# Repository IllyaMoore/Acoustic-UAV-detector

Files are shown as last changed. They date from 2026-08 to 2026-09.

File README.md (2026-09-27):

# Acoustic UAV Detector



A passive acoustic drone detector: three MEMS microphones on a 150 mm triangle
and an ESP32 that estimates the bearing to a drone from propeller noise
(TDOA, GCC-PHAT), over 360°. Several nodes can be fused into a position and
shown in ATAK.

It emits nothing, so it works without GNSS or radio, including under jamming,
and needs no transmit permit.

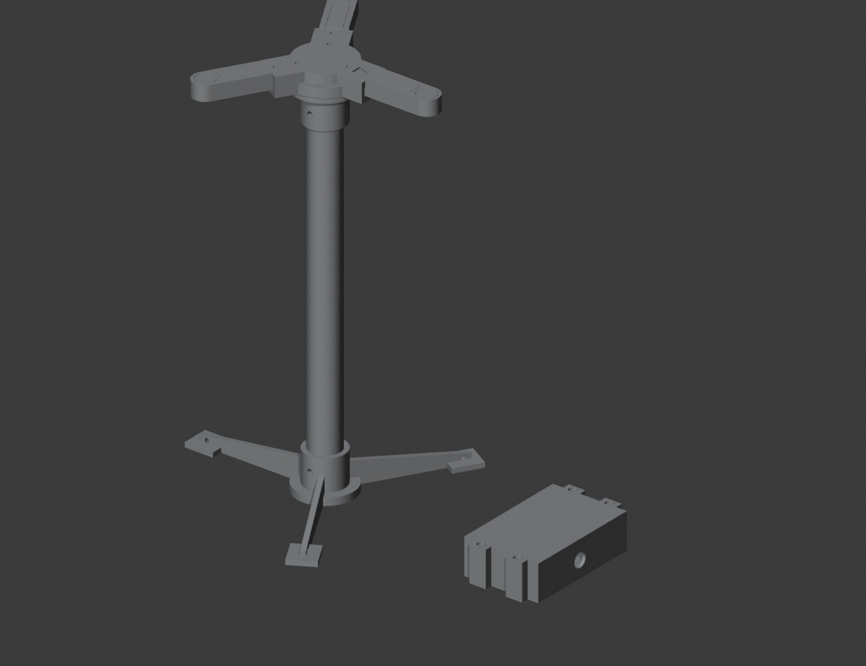
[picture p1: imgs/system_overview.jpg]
System: array on its tripod, electronics box beside it


## What's here

- [`firmware/`](firmware/): ESP-IDF, C++17, FreeRTOS, for ESP32 / ESP32-S3.
  Dual-I2S capture on one clock, GCC-PHAT on the chip, bearings out as
  NMEA-style lines, raw audio to microSD.
- [`analysis/`](analysis/): Python reference of the same DSP, a simulator, the
  clock-offset test, accuracy vs the Cramér–Rao bound, multi-node fusion, and a
  Cursor-on-Target bridge for ATAK.
- [`hardware/`](hardware/): the printed array frame and electronics box.
- [`docs/RESEARCH.md`](docs/RESEARCH.md): existing systems (Sky Fortress,
  Zvook, European vendors), signatures, datasets, choice of stack.

## Try it

No hardware needed for the first three.

```sh
make -C firmware/test/host test                  # C++ DSP unit tests
cd analysis && uv run pytest -q                  # Python reference + C++ parity
uv run python scripts/cot_bridge.py --demo --dry-run   # 3 simulated nodes -> CoT, Ctrl-C to stop
cd ../firmware && pio run -t upload              # flash an ESP32 DevKit
```

## How it works

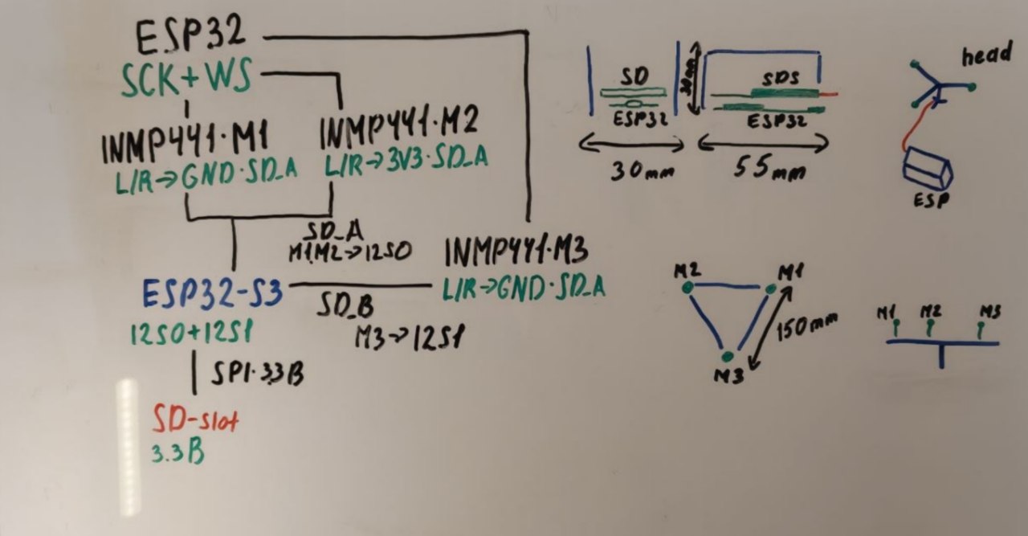
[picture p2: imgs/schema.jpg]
System schematic


**Synchronous capture.** Three mics need both of the ESP32's I2S controllers.
Only I2S0 generates the clock; I2S1 runs as a slave on the same SCK/WS. All
mics sample on the same edge, so the streams can't drift. What's left is a
constant whole-sample offset between the two controllers' buffers, which is
measured once with a click test and subtracted.

**Array.** Equilateral triangle, 150 mm sides, bearings measured clockwise from
M1. 1 mm of mic position error costs 0.38° and one sample of timing (7.1 mm)
costs 2.7°, so the frame is built to about 1 mm and the DSP interpolates to
about a tenth of a sample.

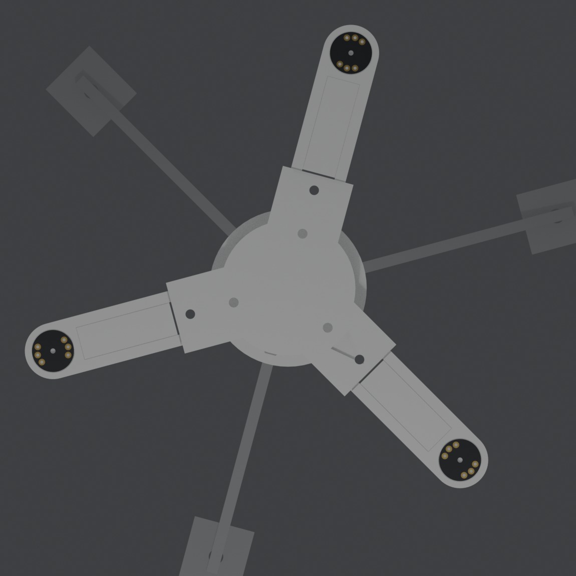
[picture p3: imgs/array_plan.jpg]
Plan view of the array


**Signal chain.** Every 21 ms the firmware reads 1024 samples per mic and
aligns them. A DSP task on the second core keeps the 200–4000 Hz bins, where
propeller and engine harmonics are and most wind isn't, and accumulates the
cross-spectra. Every 256 ms it runs GCC-PHAT per pair and solves for the
bearing. Averaging before PHAT is what holds up in wind: harmonics add
coherently, wind is local turbulence at each port and averages out.

A detection needs band energy above an adaptive noise floor, a tonal spectrum,
coherence between mics, and consistent pair delays (τ₀₁ + τ₁₂ − τ₀₂ ≈ 0).
Output, one line per block:

```
$UAVDOA,1,48213,1,62.4,152.4,18.7,0.83,11.2,0.71,1,151.9*38
        node time det az_rel az_true el conf snr coh track track_az
```

## Results (simulation)

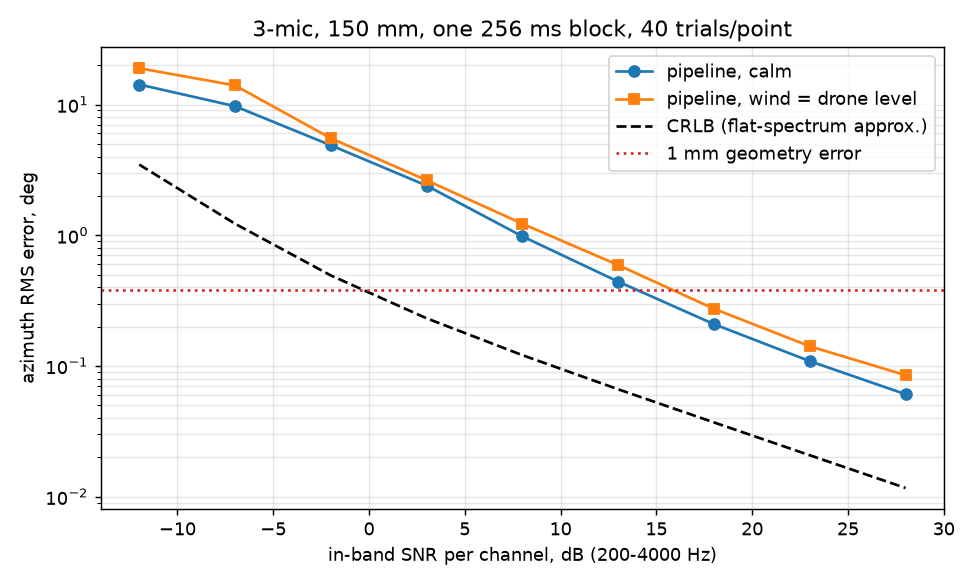
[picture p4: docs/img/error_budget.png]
Pipeline accuracy against the Cramér–Rao bound


- Bearing error under 1° above ~8 dB in-band SNR, under the 1 mm geometry
  error above ~15 dB.
- Wind as loud as the drone adds 25–35 % error.
- 5–10× above the Cramér–Rao bound. Part is the bound's flat-spectrum
  assumption, part is PHAT weighting noisy bins equally; an SNR-weighted GCC
  is the next step.

## Networked use

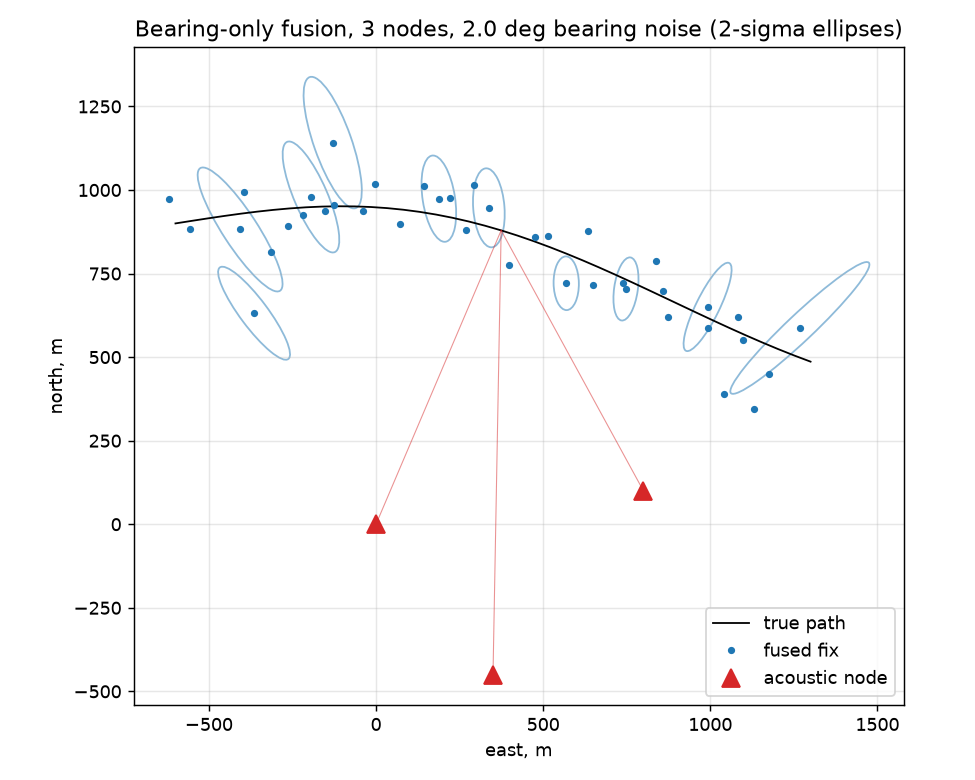
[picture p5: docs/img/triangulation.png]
Bearing-only fusion of three nodes


One node gives a bearing; two or more give a position.
`analysis/uavdoa/fusion.py` does weighted least squares with an error ellipse,
which stretches when nodes see the target from similar angles.
`analysis/scripts/cot_bridge.py` publishes nodes (with bearing wedges) and fused
fixes as Cursor-on-Target on ATAK's multicast group. Fixes are typed "unknown
air": the sensor reports a sound, the operator decides what it is.

## Testing

- ~700 host unit checks on the C++ DSP.
- The C++ and the Python reference run on the same recording and must agree to
  0.02 samples.
- The click-test gate on synthetic reboots.
- Firmware builds for both chips in CI.

## Status

The frame is printed and assembled. On the bench (September 2026) all three
mics and the SD card worked together under quick MicroPython tests.

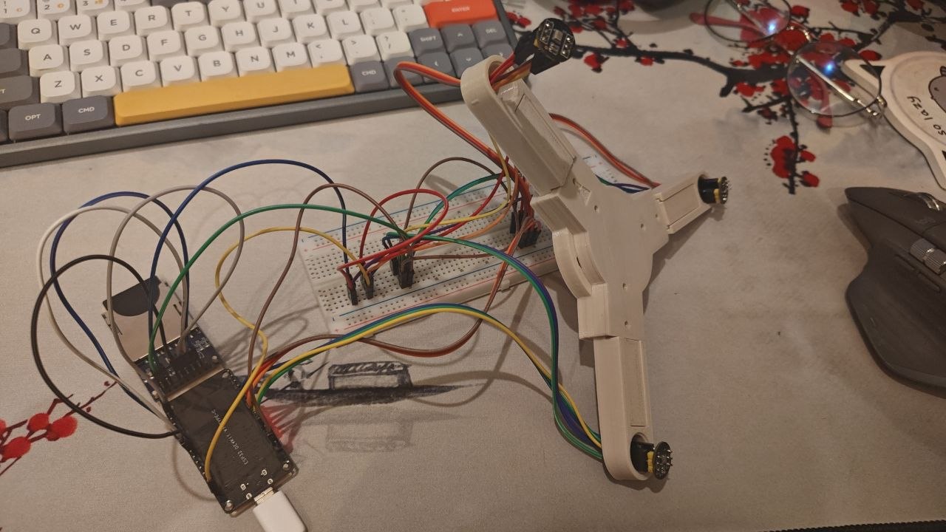
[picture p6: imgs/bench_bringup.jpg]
Bench bring-up


MicroPython's I2S is master-only, so those streams weren't sample-locked. The
firmware here implements the full design with I2S1 as a real slave. It is
tested in simulation but hasn't run on the hardware yet, because the bench
isn't currently accessible.

Next:

1. The click test on hardware. Confirm the offset between the two data lines
   is constant across reboots and over time. Nothing else matters until this
   passes.
2. Field recordings of real drones to tune the detector; there's no public
   Shahed or FPV audio.
3. SNR-weighted GCC, a small on-device classifier, time sync between nodes
   without GNSS, weatherproofing.

## Limits

- Range is hundreds of metres at best, depending on drone and background noise.
- Wind and urban noise degrade detection.
- A flat three-mic array gives azimuth plus only a rough elevation that can't
  tell above the horizon from below.
- Detection and bearing only. One node doesn't range; ranging needs several
  nodes.

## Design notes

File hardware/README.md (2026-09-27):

# Hardware

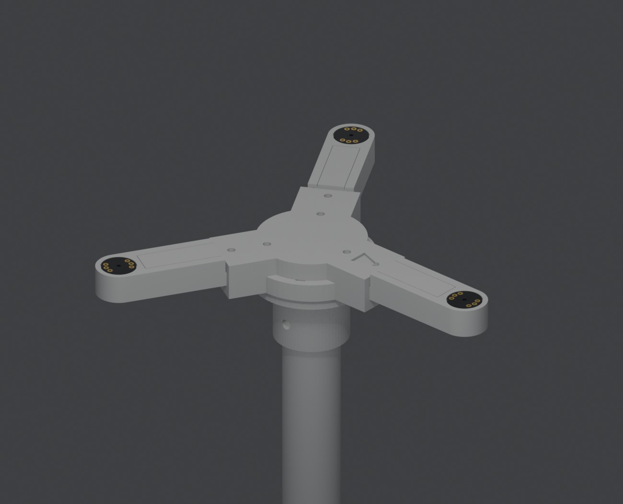
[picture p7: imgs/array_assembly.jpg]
Assembled head on the mast


## Wiring (ESP32 DevKit V1, as on the bench)

| Signal | GPIO | |
|---|---|---|
| SCK | 26 | I2S0 out, to all mics |
| WS | 25 | I2S0 out, to all mics |
| `SD_A` (M1 + M2) | 33 | I2S0 data in |
| `SD_B` (M3) | 32 | I2S1 data in |
| SCK return | 14 | I2S1 clock in, jumpered from SCK |
| WS return | 27 | I2S1 WS in, jumpered from WS |
| SD card SCK / MISO / MOSI / CS | 18 / 19 / 23 / 5 | VSPI |

L/R straps: M1 to GND, M2 to 3V3, M3 to GND. Everything runs on 3.3 V. An
unpowered INMP441 clamps its data line to zero, so a dead channel usually means
a missing VDD.

## Frame

Three PETG arms on a two-plate hub, on a Ø25 mm tube. Mics sit flush in 15.6 mm
recesses at the tips, 86.6 mm from the centre, port up. Each arm's radius is set
by a hard stop in the hub pocket, not by the bolts. The M1 arm is engraved on
the hub. Print all three arms from one file and one spool so their errors are
common-mode.

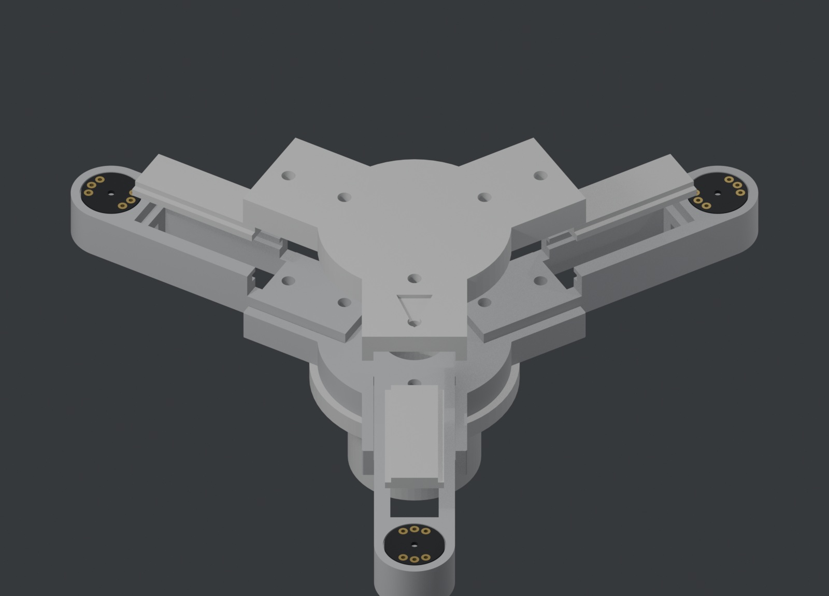
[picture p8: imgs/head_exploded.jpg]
Head opened up: plates, arm lids, boards in their seats


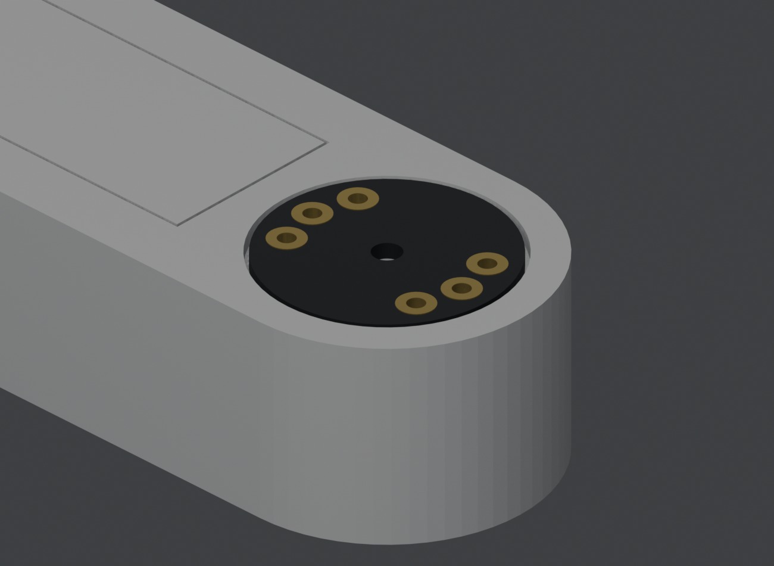
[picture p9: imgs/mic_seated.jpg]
Arm tip


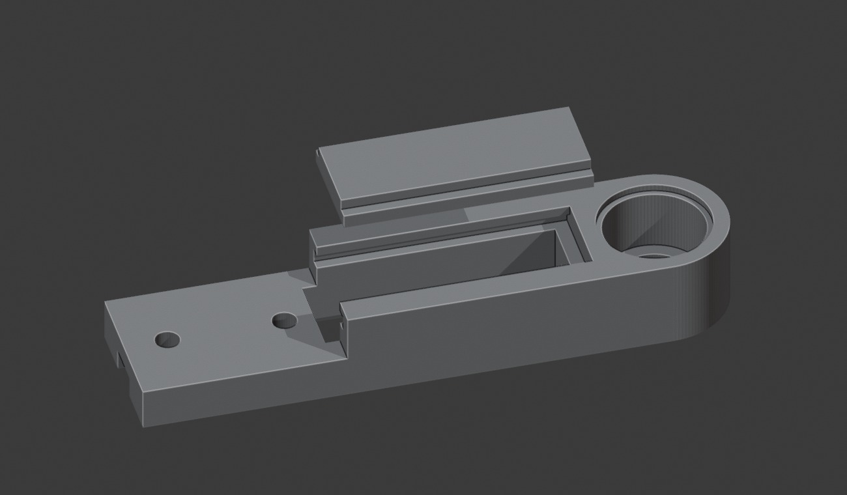
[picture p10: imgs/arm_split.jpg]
Arm body and slide-in lid


| STL | Qty |
|---|---|
| `arm_body_v4_mic15.stl` + `arm_lid_v2_mic15_slide.stl` (or one-piece `arm_v4_mic15.stl`) | 3 |
| `hub_top_v1.stl`, `hub_bottom_v3.stl` | 1 each |
| `tube_collar_top_v3.stl`, `tube_foot_v2_tube25.stl` | 1 each |
| `case_base_v2_63x108.stl`, `case_lid_v2_63x108.stl` | 1 each |
| `case_clamp_v2.stl` | 2 |

Fasteners:

| Qty | Part | For |
|---|---|---|
| 3 | M3×16 + nuts | arms |
| 3 | M3×7 | mast fitting, into the arms' inner nuts |
| 1 | M4×40 + nyloc | through the tube |
| 4 | M3×30 + nuts | box lid |
| 2 | M3×16 + nuts | board clamps |

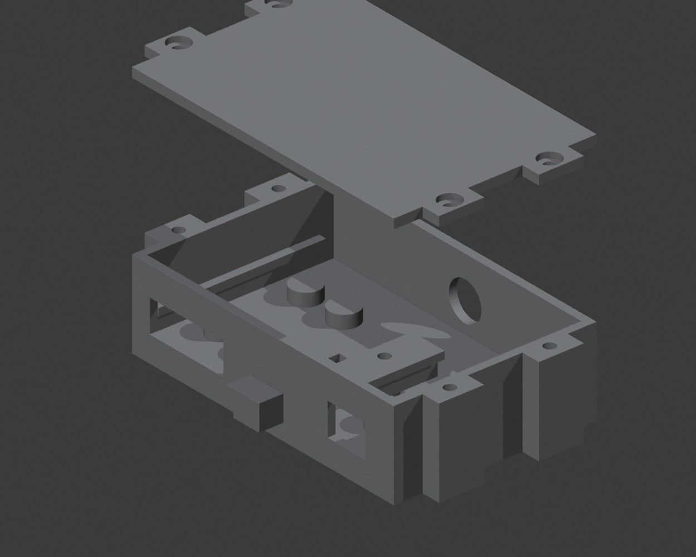
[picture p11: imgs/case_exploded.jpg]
Electronics box


Printing: 0.2 mm layers, 4 perimeters, 30 % gyroid, no supports, STLs saved in
print orientation. The widest bridges are the box's window lintels (14 and
27 mm). Older versions are in `superseded/`; don't print them.

## Open issues

- Windscreens and rain protection for the up-facing ports aren't designed yet.
- The box stands next to the tripod, so the I2S lines are much longer than the
  10–15 cm the INMP441 likes. Outdoors that needs twisted or shielded cable, or
  the electronics moved under the hub.

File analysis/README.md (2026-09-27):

# Analysis

Python reference for the firmware DSP, tools for SD-card recordings, and the
host side (fusion, ATAK bridge).

```sh
cd analysis
uv run pytest -q     # includes the C++ vs Python check, needs g++
```

On a filesystem without symlinks (exFAT/NTFS) set
`UV_PROJECT_ENVIRONMENT=/somewhere/else/venv`.

| Module | |
|---|---|
| `geometry` | mic positions, azimuth convention |
| `gccphat` | single-frame GCC-PHAT |
| `doa` | bearing from three pair delays |
| `pipeline` | mirror of `firmware/components/dsp` |
| `simulate` | drone harmonics, uncorrelated wind, exact fractional delays, FIFO offset |
| `crlb` | Cramér–Rao bounds |
| `fusion` | multi-node triangulation with covariance |
| `nmea`, `cot` | parse `$UAVDOA`, build CoT XML |
| `wavio` | the SD card WAV format |

| Script | |
|---|---|
| `simulate_wav.py` | synthetic recording |
| `localize.py` | bearings over time from a WAV, optional plot |
| `click_test.py` | checks the SD_A/SD_B offset is constant, prints `UAV_M3_LAG_SAMPLES` |
| `error_budget.py` | accuracy vs SNR against the bound → `docs/img/error_budget.png` |
| `triangulate.py` | 3-node demo → `docs/img/triangulation.png` |
| `cot_bridge.py` | serial `$UAVDOA` → CoT over UDP multicast |

Without hardware:

```sh
uv run python scripts/simulate_wav.py /tmp/s.wav --az 250 --wind 0 --offset 3 --seconds 6
uv run python scripts/click_test.py --demo
uv run python scripts/localize.py /tmp/s.wav --m3-lag 3 --plot /tmp/s.png
../firmware/test/host/build/doa_cli /tmp/s.wav --m3-lag 3
uv run python scripts/cot_bridge.py --demo --dry-run
```

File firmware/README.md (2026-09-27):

# Firmware

ESP-IDF, C++17, built with PlatformIO. Two targets: `esp32dev` (the WROOM-32
DevKit V1, default) and `esp32s3`. Why not Arduino or Rust:
[docs/RESEARCH.md](../docs/RESEARCH.md#firmware-stack).

```sh
pio run                   # build esp32dev
pio run -t upload         # flash
pio device monitor        # logs + $UAVDOA lines
pio run -t menuconfig     # "Acoustic UAV detector" menu
pio run -e esp32s3
make -C test/host test    # DSP unit tests on the PC, no board needed
```

## Layout

```
components/dsp/   no hardware dependencies, also built on the host
  fft             radix-2 complex FFT
  gcc_phat        PHAT peak by evaluating only the physical lags
  doa             pair delays -> azimuth, |elevation|, closure check
  pipeline        framing, cross-spectrum averaging, detector, tracker
  aligner         removes the fixed SD_A/SD_B offset
main/             hardware
  capture         I2S0 master + I2S1 slave
  sd_logger       WAV + detections.csv, own task
  report          $UAVDOA / $UAVCAL lines
  board_pins.hpp  WROOM-32 and S3 pin maps
test/host/        unit tests, and doa_cli which runs the pipeline on a WAV
```

`doa_cli` runs the exact on-chip DSP over a recording pulled off the SD card,
so thresholds can be tuned without reflashing.

## Tasks

| Task | Core | Prio | Does |
|---|---|---|---|
| capture | 0 | 10 | reads both I2S, aligns, sends frames to dsp, audio to the SD ring |
| sd_logger | 0 | 3 | writes `rec_NNNNN.wav` and `detections.csv` |
| dsp | 1 | 8 | pipeline, prints `$UAVDOA`, drives the LED |

Capture never waits. If DSP falls behind it drops a frame, if the card stalls it
drops an audio chunk, and both counts show up in a status log every 10 s along
with the measured DSP load. Memory is a fixed 4-frame pool and a 64 kB ring
buffer, about 82 kB of static RAM on the WROOM-32. The WAV keeps the raw offset
so it can be re-measured later; only the DSP path is aligned.

## Config (menuconfig)

| Option | Default | |
|---|---|---|
| `UAV_NODE_ID` | 1 | |
| `UAV_ARRAY_HEADING_DEG` | 0 | true heading of the M1 arm |
| `UAV_M3_LAG_SAMPLES` | 0 | from the click test |
| `UAV_CLOCK_LOOPBACK_*` | external | jumper wires, or internal via the GPIO matrix |
| `UAV_SWAP_SD_A_SLOTS` | n | if M1 shows up on channel 2 |
| `UAV_RECORD_WAV` | y | 3 ch, 16 bit, 48 kHz = 288 kB/s |
| `UAV_WAV_FILE_SECONDS` | 60 | header rewritten every 2 s, survives power loss |
| `UAV_WAV_GAIN_BITS` | 2 | shift before cutting 24 bits to 16 |
| `UAV_CALIBRATION_MODE` | n | click test: 500–8000 Hz, no alignment, prints `$UAVCAL` |
| `UAV_STATUS_LED_GPIO` | 2 / -1 | onboard LED on the WROOM devkit |

Clock return jumpers for the external mode:

| | WROOM-32 | ESP32-S3 |
|---|---|---|
| SCK to I2S1 | GPIO26 → GPIO14 | GPIO16 → GPIO4 |
| WS to I2S1 | GPIO25 → GPIO27 | GPIO15 → GPIO5 |

On the bench GPIO14/27 used to drive M3's clock from a second master. Here they
are inputs, so M3's SCK/WS have to move to GPIO26/25 first or M3 gets no clock.

## Output

```
$UAVDOA,<node>,<uptime_ms>,<det>,<az_rel>,<az_true>,<el>,<conf>,<snr_db>,<coh>,<trk>,<trk_az_true>*HH
$UAVDOA,1,48213,1,62.4,152.4,18.7,0.83,11.2,0.71,1,151.9*38
```

One line per 256 ms, NMEA-style XOR checksum, `el` is -1 when undefined.
`analysis/scripts/cot_bridge.py` turns these into CoT for ATAK.

## Bring-up

1. Flash, open the monitor, check 0 dropped frames. Scope SCK (3.072 MHz) and
   WS (48 kHz) at the far mic.
2. Tap each mic with a pencil and look at the WAV (Audacity is fine): M1 on
   channel 1, M2 on 2, M3 on 3. If M1 and M2 are swapped, set
   `UAV_SWAP_SD_A_SLOTS`.
3. Click test: calibration mode on, clicks above the centroid, a dozen reboots,
   then `analysis/scripts/click_test.py rec_*.wav`. Copy the value into
   `UAV_M3_LAG_SAMPLES`, calibration mode off.
4. Play drone audio from a speaker at known bearings 3–5 m away. A constant
   error means the heading, mic coordinates or channel map is wrong.
5. Outdoors with windscreens: record, replay through `doa_cli`, retune the
   thresholds in `PipelineConfig`.

None of this has been done with this firmware yet. Expect step 2 and 3 to turn
up problems in `capture.cpp` (slot order, slave start-up).

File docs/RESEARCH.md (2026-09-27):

# Research notes

Reading done before writing the firmware, September 2026. Unverified items are
marked.

## Who else does this

Acoustic detection got serious in Ukraine because it's cheap, passive and
ignores jamming.

- **Sky Fortress.** A microphone and a phone on a pole, roughly 9,500–14,000
  nodes at $400–1,000 each, fused centrally and pushed to mobile fire teams.
  [Defense One](https://www.defenseone.com/defense-systems/2024/07/ukraines-cheap-sensors-are-helping-troops-fight-waves-russian-drones/398204/),
  [United24](https://united24media.com/war-in-ukraine/sky-fortress-ukraines-acoustic-detection-system-that-tracks-drones-cheap-and-fast-9451)
- **Zvook.** Acoustic mirrors on 10–12 m masts along the border, feeding the
  Delta system in about 12 s; newer FPV and vehicle-mounted sensors.
  [United24](https://united24media.com/defense-tech/ukraines-zvook-acoustic-system-tests-mobile-detection-of-low-flying-missiles-and-drones-21587),
  [Unmanned Airspace](https://www.unmannedairspace.info/counter-uas-systems-and-policies/ukrainian-start-up-zvook-launches-new-low-cost-c-uas-acoustic-sensor/)
- **Europe.** Squarehead Discovair (128 mics plus camera,
  [sqhead.com](https://www.sqhead.com/drone-detection)), Monava
  ([tech.eu](https://tech.eu/2026/08/04/monava-closes-funding-round-as-demand-for-passive-drone-detection-grows/)),
  Neuron Soundware Sound Shield at €100–150 per sensor
  ([TNW](https://thenextweb.com/news/neuron-soundware-sound-shield-acoustic-drone-detection-czech-ai)).

The pattern is many cheap nodes, each reporting a bearing with a confidence,
fused centrally and delivered into an existing C2 tool (Delta, TAK). The
software here follows that: the node sends a bearing line, the host fuses and
publishes CoT.

## Signatures

- Electric multirotors and FPV: blade-pass harmonics from low hundreds of Hz to
  a few kHz, shifting with throttle. Short range (one vendor claims 200–300 m
  for FPV, [Defense Mirror](https://defensemirror.com/news/40656/), unverified).
- Shahed-136: piston two-stroke (MD-550, a Limbach L550E derivative), strong
  harmonics around 200–2000 Hz, audible for kilometres.
  [IntechOpen](https://www.intechopen.com/chapters/1203123)
- No public Shahed or FPV recordings exist
  ([OSINTO](https://www.osinto.com/the-osborne-report/acoustic-drone-detection/)).

Hence the default 200–4000 Hz band, which also keeps most wind out.

## Processing

Usual pipeline: band-limit, detect (harmonic features or a CNN on
mel/MFCC; 98–99 % in controlled tests, much worse with distance,
[review](https://pubs.aip.org/aip/adv/article/15/12/120701/3373725/)), estimate
direction with GCC-PHAT, SRP-PHAT or MUSIC, then fuse across nodes. This repo
uses a rule-based detector (band SNR, tonality, coherence), GCC-PHAT with
cross-spectra averaged over 256 ms, and weighted least-squares fusion. The
closest paper I found is
[Acta Acustica 2026](https://acta-acustica.edpsciences.org/articles/aacus/full_html/2026/01/aacus250134/aacus250134.html)
(MEMS mics, TDOA, random-forest classifier; read the abstract only).

## Open source

| Project | Licence | Use |
|---|---|---|
| [ESP-IDF](https://github.com/espressif/esp-idf) `i2s_std` | Apache-2.0 | capture, I2S1 as slave |
| [esp-dsp](https://github.com/espressif/esp-dsp) | Apache-2.0 | possible faster FFT later ([benchmarks](https://docs.espressif.com/projects/esp-dsp/en/latest/esp32/esp-dsp-benchmarks.html)) |
| [pyroomacoustics](https://github.com/LCAV/pyroomacoustics) | MIT | room/reflection simulation, SRP/MUSIC comparison |
| [ODAS](https://github.com/introlab/odas) | MIT | reference embedded SRP-PHAT and tracker |
| [PyTAK](https://github.com/snstac/pytak) | Apache-2.0 | if TLS to a TAK Server is needed |
| TFLite Micro, ESP-NN, ESP-DL | Apache-2.0 (ESP-DL unverified) | future on-device classifier |

Datasets: [DroneAudioSet](https://huggingface.co/datasets/ahlab-drone-project/DroneAudioSet/)
(MIT, 23.5 h, recorded on the drone),
[Al-Emadi](https://github.com/saraalemadi/DroneAudioDataset) (no licence,
cite only), [DREGON](https://dregon.inria.fr/) (academic use),
[DDL](https://zenodo.org/records/6459183) (licence not checked).

## Firmware stack

| Option | Verdict |
|---|---|
| Arduino-ESP32 | No: its I2S library has no slave mode ([#9945](https://github.com/espressif/arduino-esp32/issues/9945)) |
| Rust `esp-hal` | Not yet: I2S is `unstable` and master-only as of 1.2 ([docs](https://docs.rs/esp-hal/latest/esp_hal/i2s/index.html)) |
| Rust `esp-idf-hal` | Wraps the IDF driver; slave support not checked |
| MicroPython | Too slow for the DSP, and its I2S is master-only (confirmed on the bench) |
| **ESP-IDF C++** | Chosen: documented slave role, pinned tasks per core, esp-dsp/ESP-NN available |

IDF has had slave-mode bugs ([#15497](https://github.com/espressif/esp-idf/issues/15497),
[#6784](https://github.com/espressif/esp-idf/issues/6784)), so the firmware
starts the slave before the master and treats the offset as something to
measure.

## Compute (estimate)

Per 21 ms frame: three 2048-point FFTs and cross-spectra over ~160 bins. Every
256 ms: GCC-PHAT evaluated at 45 lags × ~160 bins per pair (about 7k complex
MACs), instead of three inverse FFTs. My guess is 10–15 % of one core on the
ESP32; the firmware logs the real figure every 10 s. Band-pass is done by
dropping FFT bins, since a 256-tap FIR on three channels would eat most of a
core.

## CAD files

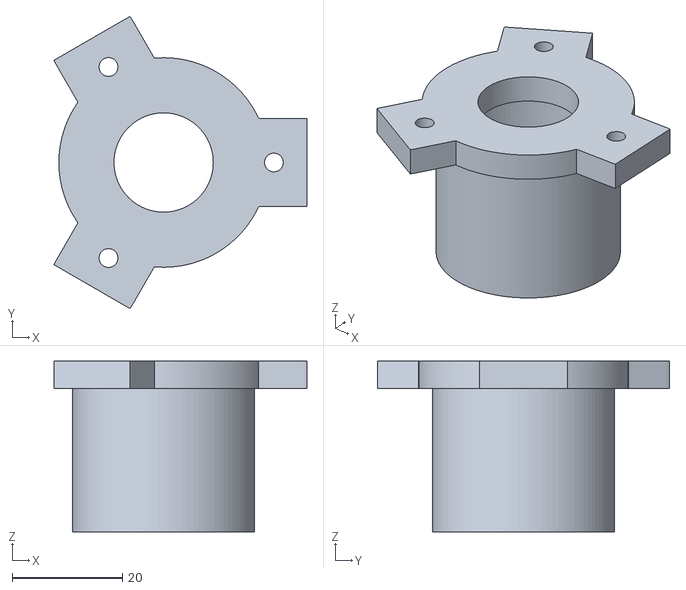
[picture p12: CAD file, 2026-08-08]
hardware/tube_collar_top_v3.stl
45.9 x 53.0 x 31.0

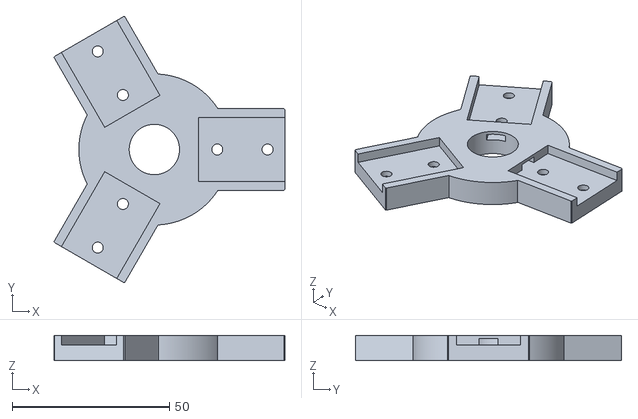
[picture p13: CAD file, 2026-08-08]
hardware/hub_bottom_v3.stl
73.4 x 84.6 x 8.00

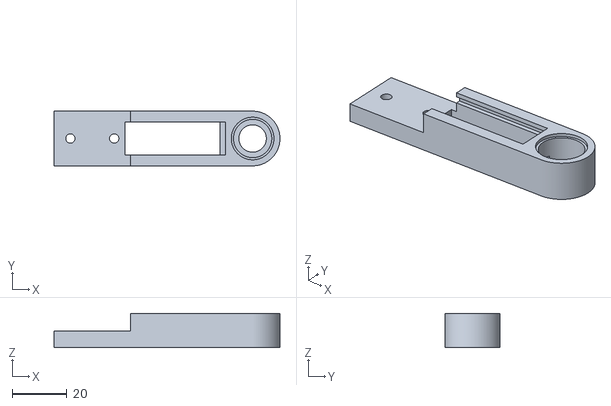
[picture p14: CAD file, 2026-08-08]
hardware/arm_body_v4_mic15.stl
82.6 x 20.0 x 12.5

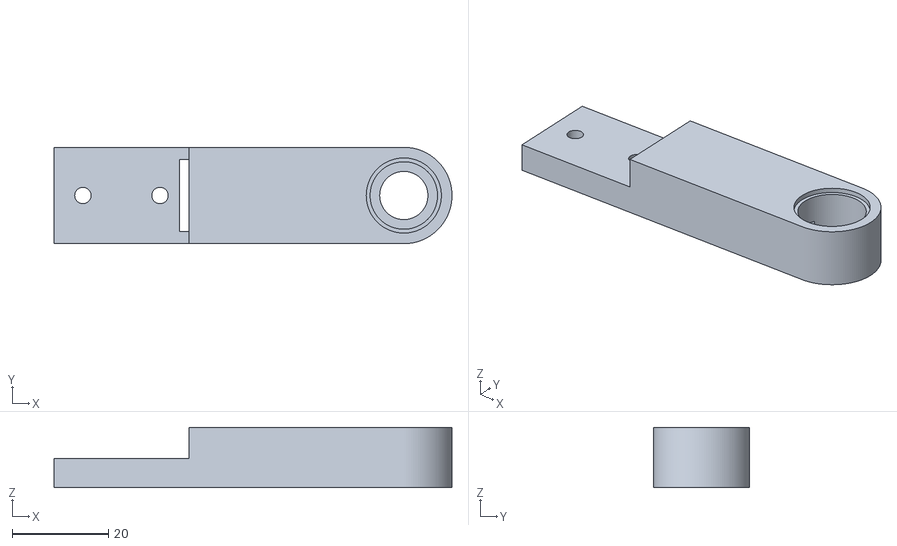
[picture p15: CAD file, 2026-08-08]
hardware/arm_v4_mic15.stl
82.6 x 20.0 x 12.5

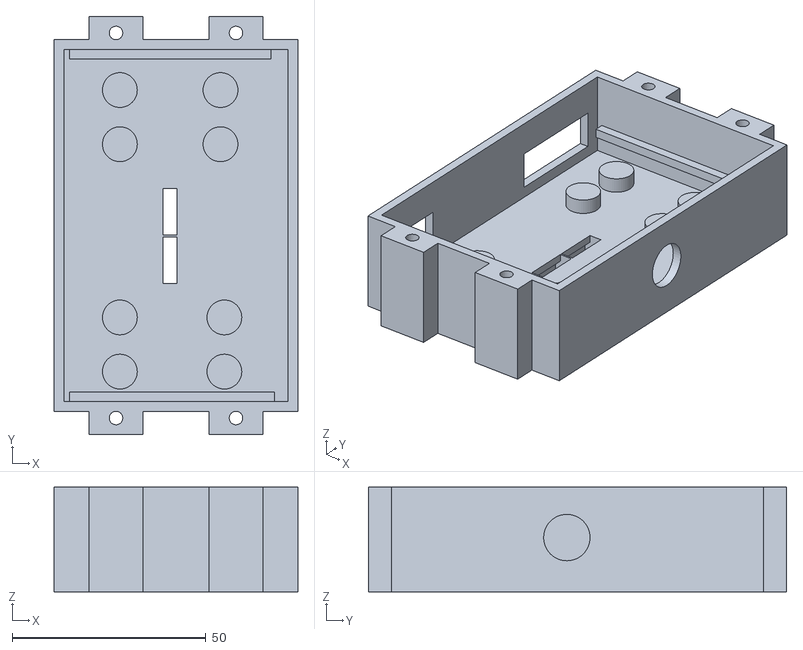
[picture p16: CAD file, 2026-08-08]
hardware/case_base_v2_63x108.stl
63.0 x 108.0 x 27.0

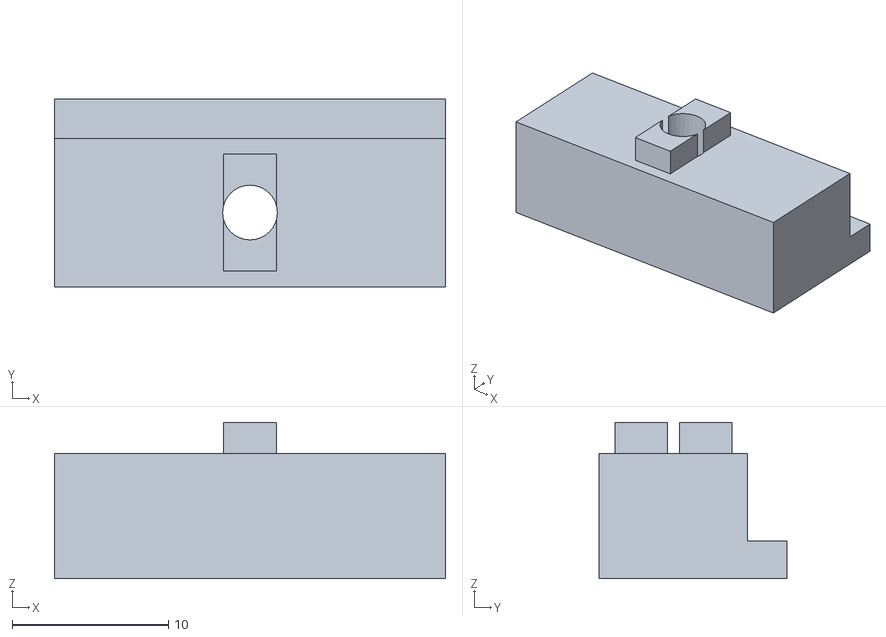
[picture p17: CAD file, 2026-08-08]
hardware/case_clamp_v2.stl
25.0 x 12.0 x 10.0

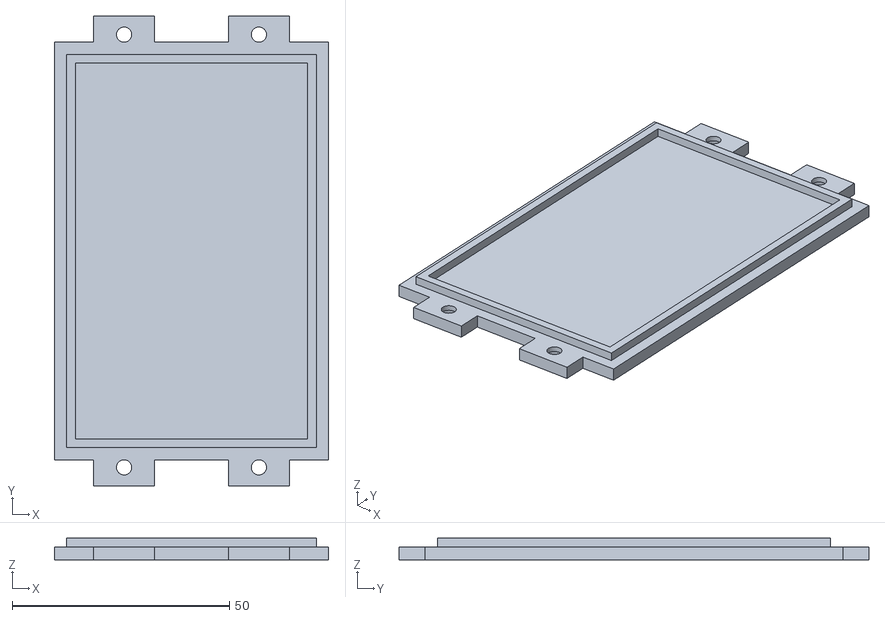
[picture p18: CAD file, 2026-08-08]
hardware/case_lid_v2_63x108.stl
63.0 x 108.0 x 5.00

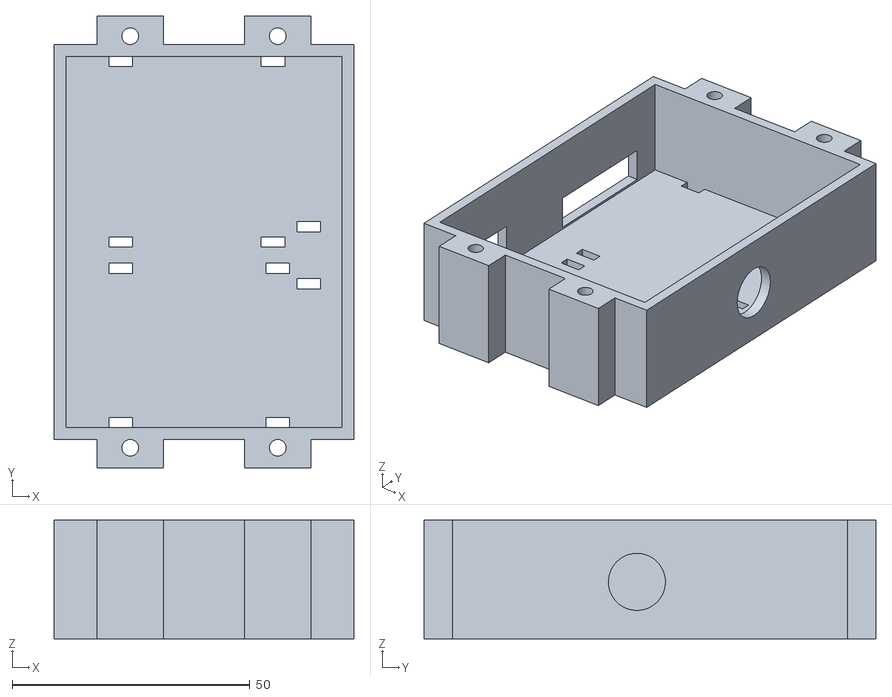
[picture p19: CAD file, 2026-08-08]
hardware/case_base_v1_63x95.stl
63.0 x 95.0 x 25.0

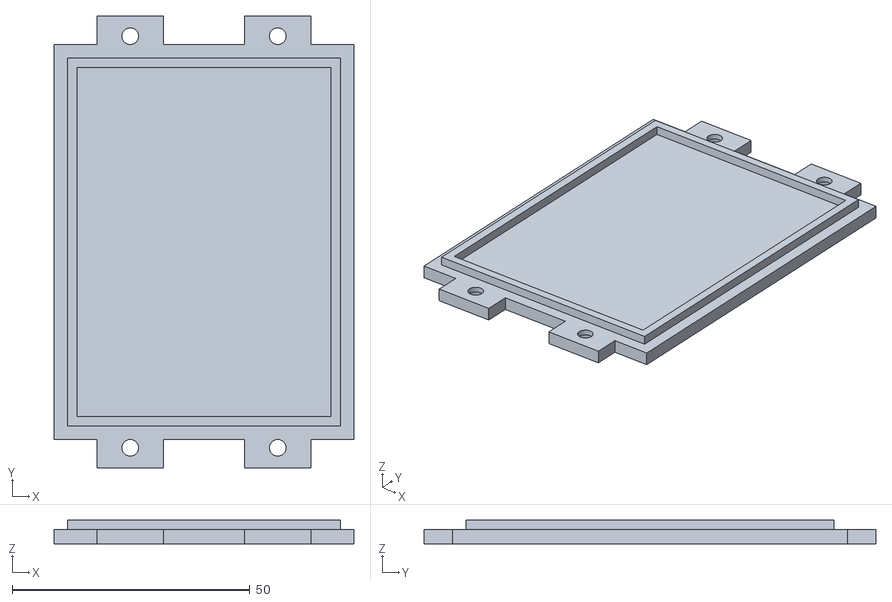
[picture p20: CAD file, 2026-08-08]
hardware/case_lid_v1_63x95.stl
63.0 x 95.0 x 5.00

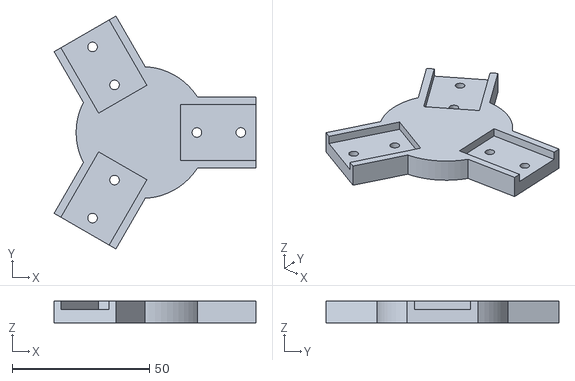
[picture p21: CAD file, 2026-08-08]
hardware/hub_top_v1.stl
73.5 x 84.9 x 8.00

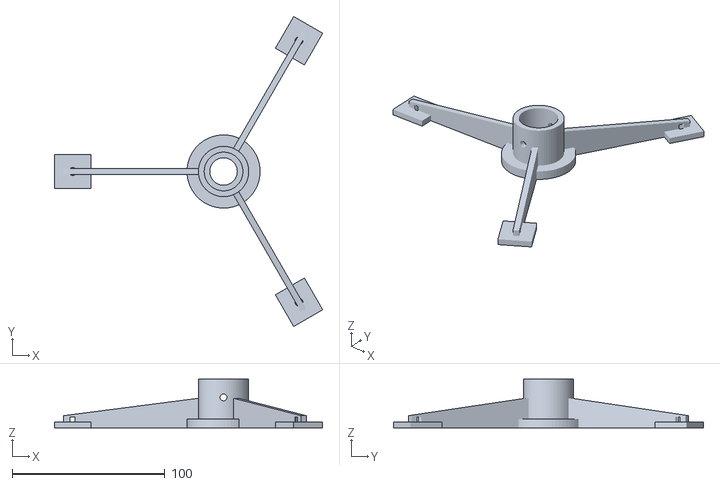
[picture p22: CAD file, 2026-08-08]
hardware/tube_foot_v2_tube25.stl
176.0 x 203.3 x 32.0

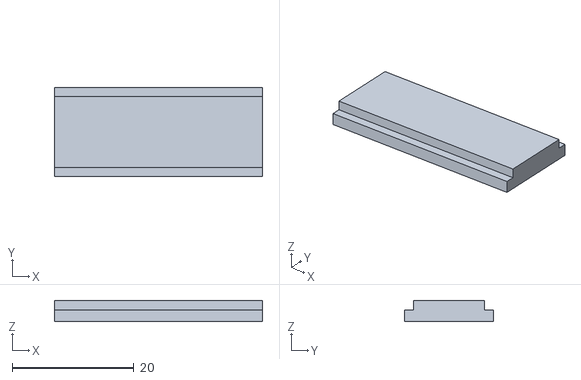
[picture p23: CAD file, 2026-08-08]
hardware/arm_lid_v2_mic15_slide.stl
34.2 x 14.6 x 3.50

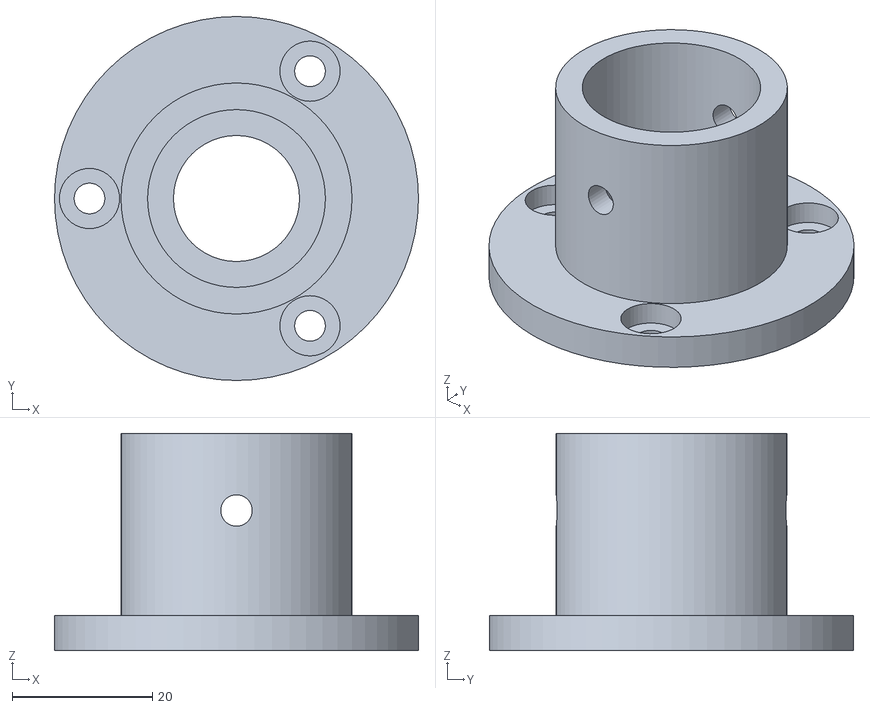
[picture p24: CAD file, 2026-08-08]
hardware/tube_collar_top_v2_tube25.stl
52.0 x 52.0 x 31.0

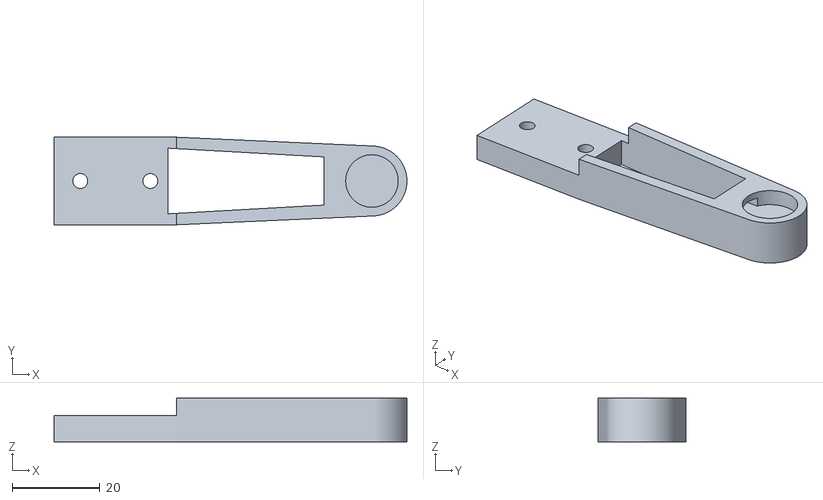
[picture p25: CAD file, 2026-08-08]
hardware/arm_body_v1_mic13.stl
80.6 x 20.0 x 10.0

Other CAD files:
hardware/arm_lid_v1_mic13_glued.stl
hardware/arm_v1_mic13.stl
hardware/superseded/hub_bottom_v2.stl
hardware/superseded/arm_body_v3_mic15.stl
hardware/arm_body_v2_mic15.stl
hardware/arm_body_v3_mic15.stl
hardware/arm_v2_mic15.stl
hardware/arm_v3_mic15.stl
hardware/hub_bottom_v1.stl
hardware/hub_bottom_v2.stl
hardware/superseded/arm_body_v2_mic15.stl
hardware/superseded/arm_lid_v1_mic13_glued.stl
hardware/superseded/arm_v1_mic13.stl
hardware/superseded/arm_v2_mic15.stl
hardware/superseded/arm_v3_mic15.stl
hardware/superseded/hub_bottom_v1.stl
hardware/superseded/tube_collar_top_v1_tube25.stl
hardware/superseded/tube_foot_v1_tube25.stl
hardware/tube_collar_top_v1_tube25.stl
hardware/tube_foot_v1_tube25.stl

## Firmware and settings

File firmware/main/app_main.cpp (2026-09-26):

// Acoustic UAV detector - firmware entry point.
//
// Three tasks, pinned so the hard-real-time part never shares a core with the
// number crunching:
//
//   core 0  capture   (prio 10)  I2S0+I2S1 -> align -> float frame -> dsp queue
//                                                     -> int16 chunk -> SD ring
//   core 0  sd_logger (prio 3)   ring -> rec_NNNNN.wav, lines -> detections.csv
//   core 1  dsp       (prio 8)   frames -> uav::Pipeline -> $UAVDOA on UART
//
// Frames travel through a small fixed pool (no malloc in the steady state).
// If DSP ever falls behind, capture drops a whole frame and counts it; it
// never blocks the I2S DMA, which would lose samples silently instead.
#include <cmath>
#include <cstdio>
#include <cstring>

#include "capture.hpp"
#include "dsp/aligner.hpp"
#include "dsp/pipeline.hpp"
#include "driver/gpio.h"
#include "esp_log.h"
#include "esp_timer.h"
#include "freertos/FreeRTOS.h"
#include "freertos/queue.h"
#include "freertos/task.h"
#include "report.hpp"
#include "sd_logger.hpp"
#include "sdkconfig.h"

namespace {
const char *TAG = "main";

constexpr std::size_t kFrameLen = 1024;  // 21.3 ms at 48 kHz
constexpr int kPoolSize = 4;

struct Frame {
    float ch[uav::kNumMics][kFrameLen];
};

Frame g_pool[kPoolSize];
QueueHandle_t g_free;    // Frame* ready to be filled
QueueHandle_t g_filled;  // Frame* ready for DSP
ArrayCapture g_capture;
SdLogger g_logger;
volatile uint32_t g_frames_dropped = 0;

#ifdef CONFIG_UAV_RECORD_WAV
constexpr bool kRecordWav = true;
constexpr int kWavSeconds = CONFIG_UAV_WAV_FILE_SECONDS;
constexpr int kWavGainBits = CONFIG_UAV_WAV_GAIN_BITS;
#else
constexpr bool kRecordWav = false;
constexpr int kWavSeconds = 60;
constexpr int kWavGainBits = 0;
#endif

#ifdef CONFIG_UAV_CALIBRATION_MODE
constexpr bool kCalibration = true;
#else
constexpr bool kCalibration = false;
#endif

uint32_t uptime_ms() { return static_cast<uint32_t>(esp_timer_get_time() / 1000); }

int16_t to_int16(int32_t raw) {
    // Top 16 of the 24 significant bits, shifted up by the configured gain.
    int32_t v = raw >> (16 - kWavGainBits);
    return static_cast<int16_t>(v > 32767 ? 32767 : (v < -32768 ? -32768 : v));
}

void capture_task(void *) {
    static int32_t raw[uav::kNumMics][kFrameLen];
    static int16_t pcm[kFrameLen * uav::kNumMics];
    // The raw WAV keeps the FIFO offset (so it can be re-measured offline);
    // only the DSP path is aligned. In calibration mode nothing is aligned.
    uav::ChannelAligner aligner(kCalibration ? 0 : CONFIG_UAV_M3_LAG_SAMPLES);

    for (;;) {
        if (g_capture.read_frame(raw[0], raw[1], raw[2]) != ESP_OK) continue;

        if (kRecordWav) {
            for (std::size_t k = 0; k < kFrameLen; ++k)
                for (int m = 0; m < uav::kNumMics; ++m) pcm[k * uav::kNumMics + m] = to_int16(raw[m][k]);
            g_logger.push_audio(pcm, kFrameLen * uav::kNumMics);
        }

        Frame *f = nullptr;
        if (xQueueReceive(g_free, &f, 0) != pdTRUE) {
            g_frames_dropped = g_frames_dropped + 1;
            continue;
        }
        constexpr float kScale = 1.0f / 2147483648.0f;
        for (int m = 0; m < uav::kNumMics; ++m)
            for (std::size_t k = 0; k < kFrameLen; ++k) f->ch[m][k] = static_cast<float>(raw[m][k]) * kScale;
        float *x[uav::kNumMics] = {f->ch[0], f->ch[1], f->ch[2]};
        aligner.process(x, kFrameLen);
        xQueueSend(g_filled, &f, portMAX_DELAY);
    }
}

void set_led(bool on) {
    if (CONFIG_UAV_STATUS_LED_GPIO >= 0) gpio_set_level(static_cast<gpio_num_t>(CONFIG_UAV_STATUS_LED_GPIO), on);
}

void dsp_task(void *) {
    uav::PipelineConfig cfg;
    cfg.fs = ArrayCapture::kSampleRate;
    cfg.frame_len = kFrameLen;
    if (kCalibration) {
        cfg.f_lo = 500.0f;  // clicks are broadband; wider band, sharper peak
        cfg.f_hi = 8000.0f;
    }
    uav::Pipeline pipeline(cfg);
    ESP_LOGI(TAG, "pipeline: band %.0f-%.0f Hz (%u bins), max lag %d, block %.0f ms", cfg.f_lo, cfg.f_hi,
             static_cast<unsigned>(pipeline.n_bins()), pipeline.max_lag(),
             1000.0f * cfg.frame_len * cfg.avg_frames / cfg.fs);

    uav::BlockResult r;
    char line[160];
    int64_t busy_us = 0, window_start = esp_timer_get_time();
    for (;;) {
        Frame *f = nullptr;
        xQueueReceive(g_filled, &f, portMAX_DELAY);
        const int64_t t0 = esp_timer_get_time();
        const float *x[uav::kNumMics] = {f->ch[0], f->ch[1], f->ch[2]};
        const bool block_done = pipeline.push_frame(x, r);
        xQueueSend(g_free, &f, portMAX_DELAY);
        if (!block_done) {
            busy_us += esp_timer_get_time() - t0;
            continue;
        }

        const uint32_t now = uptime_ms();
        const std::size_t n = kCalibration
                                  ? report::format_cal(line, sizeof line, CONFIG_UAV_NODE_ID, now, r)
                                  : report::format_doa(line, sizeof line, CONFIG_UAV_NODE_ID, now, r,
                                                       CONFIG_UAV_ARRAY_HEADING_DEG);
        std::fwrite(line, 1, n, stdout);
        set_led(r.detected);

        if (r.detected) {
            std::snprintf(line, sizeof line, "%lu,%d,1,%.1f,%.1f,%.1f,%.2f,%.1f,%.2f",
                          static_cast<unsigned long>(now), CONFIG_UAV_NODE_ID, r.bearing.az_deg,
                          uav::wrap_deg(r.bearing.az_deg + CONFIG_UAV_ARRAY_HEADING_DEG),
                          std::isnan(r.bearing.el_deg) ? -1.0f : r.bearing.el_deg, r.confidence, r.snr_db,
                          r.coherence);
            g_logger.push_line(line);
        }

        busy_us += esp_timer_get_time() - t0;
        const int64_t t = esp_timer_get_time();
        if (t - window_start >= 10'000'000) {
            // Every 10 s: how much of core 1 the DSP is using, and any losses.
            ESP_LOGI(TAG, "dsp load %.1f %%, frames dropped %u, sd chunks dropped %u, free heap %u",
                     100.0 * busy_us / (t - window_start), static_cast<unsigned>(g_frames_dropped),
                     static_cast<unsigned>(g_logger.dropped_chunks()),
                     static_cast<unsigned>(esp_get_free_heap_size()));
            busy_us = 0;
            window_start = t;
        }
    }
}
}  // namespace

extern "C" void app_main(void) {
    ESP_LOGI(TAG, "acoustic UAV detector, node %d, M1 heading %d deg, M3 lag %d samples%s", CONFIG_UAV_NODE_ID,
             CONFIG_UAV_ARRAY_HEADING_DEG, CONFIG_UAV_M3_LAG_SAMPLES, kCalibration ? ", CALIBRATION MODE" : "");

    if (CONFIG_UAV_STATUS_LED_GPIO >= 0) {
        gpio_reset_pin(static_cast<gpio_num_t>(CONFIG_UAV_STATUS_LED_GPIO));
        gpio_set_direction(static_cast<gpio_num_t>(CONFIG_UAV_STATUS_LED_GPIO), GPIO_MODE_OUTPUT);
    }

    g_logger.start(ArrayCapture::kSampleRate, uav::kNumMics, kRecordWav, kWavSeconds);

    g_free = xQueueCreate(kPoolSize, sizeof(Frame *));
    g_filled = xQueueCreate(kPoolSize, sizeof(Frame *));
    for (auto &f : g_pool) {
        Frame *p = &f;
        xQueueSend(g_free, &p, 0);
    }

    ESP_ERROR_CHECK(g_capture.start(kFrameLen));

    xTaskCreatePinnedToCore(dsp_task, "dsp", 8192, nullptr, 8, nullptr, 1);
    xTaskCreatePinnedToCore(capture_task, "capture", 4096, nullptr, 10, nullptr, 0);
}

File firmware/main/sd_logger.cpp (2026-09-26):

#include "sd_logger.hpp"

#include <sys/stat.h>
#include <unistd.h>

#include <cstdio>
#include <cstring>

#include "board_pins.hpp"
#include "driver/sdspi_host.h"
#include "driver/spi_common.h"
#include "esp_log.h"
#include "esp_timer.h"
#include "esp_vfs_fat.h"
#include "freertos/FreeRTOS.h"
#include "freertos/queue.h"
#include "freertos/ringbuf.h"
#include "freertos/task.h"
#include "sdmmc_cmd.h"

namespace {
const char *TAG = "sd";
constexpr char kMount[] = "/sd";
constexpr std::size_t kRingBytes = 64 * 1024;  // ~220 ms of 3ch/16-bit/48 kHz
constexpr std::size_t kLineLen = 128;
constexpr int64_t kSyncEveryUs = 2'000'000;  // header rewrite + fsync period

struct Line {
    char text[kLineLen];
};

void put_u32(uint8_t *p, uint32_t v) { std::memcpy(p, &v, 4); }
void put_u16(uint8_t *p, uint16_t v) { std::memcpy(p, &v, 2); }

// Canonical 44-byte PCM header. Rewritten every couple of seconds with the
// current length, so a file cut off by a power loss is still a valid WAV
// holding everything up to the last sync.
void write_wav_header(FILE *f, uint32_t fs, int ch, uint32_t data_bytes) {
    uint8_t h[44];
    std::memcpy(h, "RIFF", 4);
    put_u32(h + 4, 36 + data_bytes);
    std::memcpy(h + 8, "WAVEfmt ", 8);
    put_u32(h + 16, 16);
    put_u16(h + 20, 1);  // PCM
    put_u16(h + 22, static_cast<uint16_t>(ch));
    put_u32(h + 24, fs);
    put_u32(h + 28, fs * ch * 2);
    put_u16(h + 32, static_cast<uint16_t>(ch * 2));
    put_u16(h + 34, 16);
    std::memcpy(h + 36, "data", 4);
    put_u32(h + 40, data_bytes);
    const long pos = std::ftell(f);
    std::fseek(f, 0, SEEK_SET);
    std::fwrite(h, 1, sizeof h, f);
    if (pos > static_cast<long>(sizeof h)) std::fseek(f, pos, SEEK_SET);
}

FILE *open_next_wav(uint32_t fs, int ch) {
    static int next = 0;
    char path[48];
    struct stat st;
    for (; next < 100000; ++next) {
        std::snprintf(path, sizeof path, "%s/rec_%05d.wav", kMount, next);
        if (stat(path, &st) != 0) break;
    }
    FILE *f = std::fopen(path, "wb");
    if (f) {
        write_wav_header(f, fs, ch, 0);
        ESP_LOGI(TAG, "recording %s", path);
        ++next;
    }
    return f;
}
}  // namespace

esp_err_t SdLogger::start(uint32_t sample_rate, int channels, bool record_wav, int file_seconds) {
    sample_rate_ = sample_rate;
    channels_ = channels;
    record_wav_ = record_wav;
    file_seconds_ = file_seconds;

    spi_bus_config_t bus = {};
    bus.mosi_io_num = pins::kSdMosi;
    bus.miso_io_num = pins::kSdMiso;
    bus.sclk_io_num = pins::kSdSck;
    bus.quadwp_io_num = -1;
    bus.quadhd_io_num = -1;
    bus.max_transfer_sz = 16 * 1024;

    sdmmc_host_t host = SDSPI_HOST_DEFAULT();
    // 20 MHz is the SPI-mode ceiling and fine on a PCB; on jumper wires drop
    // this if mounting fails intermittently.
    host.max_freq_khz = SDMMC_FREQ_DEFAULT;
    esp_err_t err = spi_bus_initialize(static_cast<spi_host_device_t>(host.slot), &bus, SDSPI_DEFAULT_DMA);
    if (err != ESP_OK) {
        ESP_LOGW(TAG, "SPI bus init failed (%s) - running without the card", esp_err_to_name(err));
        return err;
    }
    sdspi_device_config_t slot = SDSPI_DEVICE_CONFIG_DEFAULT();
    slot.gpio_cs = static_cast<gpio_num_t>(pins::kSdCs);
    slot.host_id = static_cast<spi_host_device_t>(host.slot);

    esp_vfs_fat_sdmmc_mount_config_t mount = {};
    mount.format_if_mount_failed = false;  // never wipe a card that holds recordings
    mount.max_files = 4;
    mount.allocation_unit_size = 32 * 1024;
    sdmmc_card_t *card = nullptr;
    err = esp_vfs_fat_sdspi_mount(kMount, &host, &slot, &mount, &card);
    if (err != ESP_OK) {
        ESP_LOGW(TAG, "no card (%s) - running without recording", esp_err_to_name(err));
        return err;
    }
    sdmmc_card_print_info(stdout, card);

    ring_ = xRingbufferCreate(kRingBytes, RINGBUF_TYPE_NOSPLIT);
    lines_ = xQueueCreate(16, sizeof(Line));
    if (!ring_ || !lines_) return ESP_ERR_NO_MEM;
    enabled_ = true;
    // Core 0, below capture: the writer only ever gets the leftovers.
    xTaskCreatePinnedToCore(task_entry, "sd_logger", 4096, this, 3, nullptr, 0);
    return ESP_OK;
}

void SdLogger::push_audio(const int16_t *interleaved, std::size_t n) {
    if (!enabled_ || !record_wav_) return;
    if (xRingbufferSend(static_cast<RingbufHandle_t>(ring_), interleaved, n * sizeof(int16_t), 0) != pdTRUE)
        dropped_ = dropped_ + 1;
}

void SdLogger::push_line(const char *text) {
    if (!enabled_) return;
    Line l;
    std::strncpy(l.text, text, kLineLen - 1);
    l.text[kLineLen - 1] = '\0';
    xQueueSend(static_cast<QueueHandle_t>(lines_), &l, 0);
}

void SdLogger::task_entry(void *arg) { static_cast<SdLogger *>(arg)->run(); }

void SdLogger::run() {
    auto *ring = static_cast<RingbufHandle_t>(ring_);
    auto *lines = static_cast<QueueHandle_t>(lines_);

    char csv_path[32];
    std::snprintf(csv_path, sizeof csv_path, "%s/detections.csv", kMount);
    struct stat st;
    const bool fresh = stat(csv_path, &st) != 0;
    FILE *csv = std::fopen(csv_path, "a");
    if (csv && fresh)
        std::fputs("uptime_ms,node,detected,az_rel_deg,az_true_deg,el_deg,confidence,snr_db,coherence\n", csv);

    FILE *wav = nullptr;
    uint32_t data_bytes = 0;
    const uint32_t bytes_per_file = sample_rate_ * channels_ * 2 * file_seconds_;
    int64_t last_sync = esp_timer_get_time();

    for (;;) {
        std::size_t len = 0;
        void *item = xRingbufferReceive(ring, &len, pdMS_TO_TICKS(100));
        if (item) {
            if (!wav) {
                wav = open_next_wav(sample_rate_, channels_);
                data_bytes = 0;
            }
            if (wav) {
                data_bytes += std::fwrite(item, 1, len, wav);
                if (data_bytes >= bytes_per_file) {
                    write_wav_header(wav, sample_rate_, channels_, data_bytes);
                    std::fclose(wav);
                    wav = nullptr;
                }
            }
            vRingbufferReturnItem(ring, item);
        }

        Line l;
        while (xQueueReceive(lines, &l, 0) == pdTRUE)
            if (csv) std::fprintf(csv, "%s\n", l.text);

        const int64_t now = esp_timer_get_time();
        if (now - last_sync > kSyncEveryUs) {
            last_sync = now;
            if (wav) {
                write_wav_header(wav, sample_rate_, channels_, data_bytes);
                std::fflush(wav);
                fsync(fileno(wav));
            }
            if (csv) {
                std::fflush(csv);
                fsync(fileno(csv));
            }
            if (dropped_) ESP_LOGW(TAG, "%u audio chunks dropped so far (card too slow?)",
                                   static_cast<unsigned>(dropped_));
        }
    }
}

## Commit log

2026-08-08 add: printed array frame (STLs, renders, README)
    Three-armed frame modelled and exported for PETG printing:
    - arm x3, two-plate sandwich hub, tube clamp + tripod foot
    - mast is a bought Ø25 mm tube, not printed (~15x stiffer, no tall print)
    - arm tip reworked for the INMP441 round board: flush Ø13.4 recess,
    Ø12 cavity clearing the rim pads, board mounted chip-down
    README documents the error budget (1 mm -> 0.38° of azimuth), why beam
    flex is not the limiting factor, hardware list and print settings.
    [arm.stl, hub_bottom.stl, hub_top.stl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]
2026-08-08 fix: arm print orientation, add split variant
    The arm was exported inverted, which leaves the root tab floating 6.5 mm
    above the bed and needs a support block — the README claim that no part
    needs support was wrong for it. Re-exported tab-down; the only overhang
    left is the 15 mm cable-channel ceiling, which bridges.
    Also adds arm_lid + arm_body: the same arm split along the channel
    ceiling for support-free flat printing and gluing. The split is
    horizontal on purpose, so glue-line thickness lands on arm height
    instead of on the 86.6 mm radius.
    [arm.stl, arm_body.stl, arm_lid.stl]
2026-08-08 fix: drop cable tunnel onto the cavity floor
    The tunnel sat at z -6..-3, which left only 0.5 mm of roof over it in
    arm_body (top face at -2.5) — a 5 mm bridge carried by two or three
    lines. Moved to -6..-4, so the roof is 4 mm in the whole arm and 1.5 mm
    in the split body.
    README now documents the full cable route and lists the three internal
    bridges with their spans.
    [arm.stl, arm_body.stl, arm_lid.stl]
2026-08-08 add: arm v2 for the Ø15 board, slide-in lid, versioned file names
    The board is 15 mm, not 13 — v1 was printed and would not take it. The
    Ø15.6 recess needs meat around it, so the tip goes to Ø20 and the arm to
    a constant 20 mm width.
    Two-part arm no longer needs glue. The lid is a T-bar sliding into a
    T-slot from the root end, stopping on the tip block; the hub's top plate
    closes the last degree of freedom on assembly. A slide-in lid cannot
    carry the Ø20 tip through its own slot, so the tip and the microphone
    seat moved into the body — which also removes the 15 mm channel bridge.
    Hardware files now carry an iteration number and the dimension that
    defines them. v1 is kept, not overw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
    [arm_body_v1_mic13.stl, arm_body_v2_mic15.stl, arm_lid_v1_mic13_glued.stl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]
2026-08-08 simplify: tube fittings v2, pinch clamp replaced by a through-bolt
    The v1 fittings could not be printed cleanly: the clamp ears hang 7 mm
    over the flange with nothing under them, and part of each ear overhangs
    the flange edge entirely.
    Buttressing the ear does not work — attaching it to the flange welds the
    clamp shut, since a pinch grips only because its halves are free to
    move. Slotting the flange as well would make the part a C, but the three
    M4 bolts that hold the flange to the hub would then prise it open again.
    Replaced with one M4 straight through both walls and the tube. Ears,
    pinch slot and nut pockets all disappear; both parts now grow from the
    build plate with zero unsupported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
    [tube_collar_top_v2_tube25.stl, tube_foot_v2_tube25.stl]
2026-08-08 fix: thicker retaining lip, lid printed flange down
    The lid's retaining lip was 0.8 mm — four layers. Strong enough for a 2 g
    lid, but easy to snap off while threading the lid into the slot. Lid
    pocket deepened 2.5 -> 3.5 mm and the thickness redistributed: lip 1.4,
    flange 1.95, rib 1.55. The cable channel gives up 1 mm and is still
    12 x 9 mm.
    Lid now exported flange down. The rib is the narrower section, so it
    prints on top of the wider flange with no overhang anywhere, and the
    first layer grows from 397 to 499 mm2.
    [arm_body_v2_mic15.stl, arm_lid_v2_mic15_slide.stl]
2026-08-08 fix: boolean artefacts, missing channel ceiling, cable-vs-bolt clash
    Auditing the meshes after a report of stray faces under the lid turned
    up three separate problems.
    1. Zero-thickness membrane across the lid slot. The channel, the flange
    pocket and the lip gap were three separate difference operations that
    met exactly on shared planes, leaving a 519 mm2 downward face and a
    415 mm2 upward face coincident at z=-1.4, plus zero-area slivers at
    z=-6. All voids are now unioned into a single tool with a 0.01 mm
    overlap and subtracted once. Every part audits clean: no non-manifold
    edges, no edges with >2 faces, no degenerate faces, no coincident
    opposite-facing pairs.
    2. arm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
    [arm_body_v2_mic15.stl, arm_lid_v2_mic15_slide.stl, arm_v2_mic15.stl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]
2026-08-08 verify: dimensional audit against the STLs, exact recess depth
    Measured the exported meshes rather than the Blender scene. Microphone
    seat confirmed at the Ø15 board size: recess Ø15.60, cavity Ø14.00,
    ledge 0.80 mm. Hub pockets ±10.15, plates 8.000, collar bore Ø25.40,
    flange R26.000 — all on nominal.
    One deviation found and fixed: the recess measured 1.005 mm deep instead
    of 1.000, because the 0.01 mm boolean overlap was applied on the floor
    side of the cut instead of the open side. 5 µm is a fortieth of a layer,
    but the datum is now exact.
    Screenshots regenerated from the audited geometry.
    [arm_body_v2_mic15.stl, arm_v2_mic15.stl]
2026-08-08 add: electronics box for the ESP32 and SD module
    Two parts, base and lid, standing beside the tripod. Holds the ESP32
    DevKit V1 and the SPI SD module for logging.
    Neither board has a trustworthy dimension. The ESP32 is documented at
    51.8 x 28.2 and measures 50 x 28; the SD module is listed at 50 x 33,
    measures 46 x 29, and is sold elsewhere as 41 x 24, 42 x 24 and 53 x 38
    under the same name, with no datasheet anywhere. So the box does not grip
    the boards at all: flat floor, no pockets, each board held by two cable
    ties through floor slots. Fits any of those sizes and survives a board
    swap without a reprint.
    Bays 53 x 29.5 and 52 x 35 with 8.5 mm between them. Windows for USB
    (14 x 9.5) an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
    [case_base_v1_63x83.stl, case_base_v1_63x95.stl, case_lid_v1_63x83.stl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]
2026-08-08 chore: drop mis-named intermediate case export
    case_*_v1_63x83.stl were an intermediate export of the same v1 design,
    before the feet were removed and the boolean membranes fixed — 4
    coincident face pairs, and named for a bounding box that did not include
    the lid bosses. Not a design iteration, just a defective file under a
    second name; keeping it in hardware/ would only invite printing it.
    The geometry is in git history if it is ever wanted.
    [case_base_v1_63x83.stl, case_lid_v1_63x83.stl]
2026-08-08 add: adjustable board mounting in the electronics box
    USB confirmed as Type-C; window unchanged at 14 mm, which clears the
    plug shell and its overmould.
    Board mounting is driven by the ESP32. Its headers are soldered
    underneath with ~3 mm of tail, so the board cannot sit on the floor, and
    the pin rows run along both long edges, so it cannot be supported at the
    edges either. Boards now sit on four Ø9 pads 4 mm tall in the clear
    central band, PCB underside at 9 mm, tails hanging with 1 mm to spare.
    Retention is from above only: a fixed lip moulded into the outer wall,
    and case_clamp_v2 on a T-slot at the inner edge with 12 mm of travel,
    which covers every board width anyone quotes for these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
    [case_base_v2_63x108.stl, case_clamp_v2.stl, case_lid_v2_63x108.stl]
2026-08-08 arm v3: gabled cable channel, access hole under the microphone
    The channel had a flat ceiling 15 mm wide running 32.6 mm — the largest
    unsupported span in the build. It is now 10 mm wide with a 45 deg gable
    roof closing to a ridge where the ceiling used to be, so there is nothing
    to bridge at all. Costs 2.6 g per arm; the side walls double to 5 mm and
    bed contact goes to roughly 1040 mm2.
    A Ø10 hole now runs from the cavity floor through to the underside of the
    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
    [arm_body_v3_mic15.stl, arm_v3_mic15.stl]
2026-08-08 arm v4: deeper microphone pocket, narrower grooves, rebuilt from scratch
    The board turned out to carry pins, taking the board-plus-legs stack to
    about 9 mm against a 6 mm pocket. The pocket is now 9.5 mm — the half
    millimetre is deliberate, so the board lands on its seat rather than on
    its own pin tips, which would lift it off the centring recess.
    Following from that:
    - the cable tunnel moved down onto the new cavity floor, z -9.5..-6.75,
    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
    [arm_body_v4_mic15.stl, arm_v4_mic15.stl]
2026-08-08 hub_bottom v2: cable tunnels 12 mm -> 6 mm
    Between each tab pocket and the central bore the lower plate carries a
    closed tunnel, roofed at z -10.5. It was 12 mm wide because it had been
    widened to match the arm's tab groove — and that groove is now 6 mm, so
    the widest bridge in the build had quietly moved from the arm into the
    hub. Narrowed to match; roof area per tunnel drops from 82.1 to 37.2 mm2.
    Caught one error on the way: 15.23 mm is the corner radius of the tunnel
    roof, not the position of the pocket wall, which is at x = 14.0. Filling
    to 15.23 raised the floor inside the tab pocket by 2 mm over a 1.2 mm
    strip, which the tab would have sat on. The plane-area audit showed it —
    the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
    [hub_bottom_v2.stl]
2026-08-08 docs: overhang audit across every printed part
    Swept all eleven STLs for downward-facing surfaces in the orientation
    each one is saved in, measuring span and area rather than eyeballing
    them. hub_top, tube_collar_top and tube_foot had never been checked.
    Result: nothing needs changing. The widest ceiling left anywhere is the
    engraved M1 arrow in hub_top at 8.9 mm, which faces the bed and produces
    the inside of a decorative groove. The tube fittings show only the crowns
    of their horizontal bolt holes, which no design avoids.
    The arm's bridge table was also incomplete — it never listed the 1.5 mm
    undercut the lid flange slides under. Added, with measured areas.
2026-08-08 chore: split superseded STLs into their own folder
    hardware/ now holds only the ten files worth printing; the twelve that
    have been replaced moved to hardware/superseded/. Nothing deleted —
    moved with git mv, so history follows each file.
    [arm_body_v1_mic13.stl, arm_body_v2_mic15.stl, arm_body_v3_mic15.stl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]
2026-08-08 hub_bottom v3 and tube_collar_top v3: one bolt circle instead of two
    The lower plate carried its own three M4 holes for the mast fitting,
    sitting a few millimetres from the six M3 that clamp the arms — two
    fastener sets crossing the one plate the cable also has to cross. The
    fitting now lands on the arms' inner bolt circle at r 20 and screws into
    the nuts that are already there.
    Two things fall out of that. The M4 nut traps were what forced the lower
    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
    [hub_bottom_v2.stl, hub_bottom_v3.stl, tube_collar_top_v2_tube25.stl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]
2026-09-04 docs: bench bring-up — pin map, all three mics and SD verified
    Add the concrete DevKit V1 pin assignment to the wiring section (the map
    the bench is actually wired to), record the September 2026 breadboard
    bring-up in project status with a photo, and note the unpowered-VDD
    failure mode that reads as a grounded data line.
2026-09-26 firmware: portable DSP core with host tests
    FFT, GCC-PHAT (direct lag evaluation over in-band bins, parabolic
    sub-sample fit), least-squares bearing with a closure check, and the
    block pipeline: cross-spectrum averaging, detector, tracker, and the
    FIFO-offset aligner. Hardware-free, so it builds for the ESP32 and on
    the host; doa_cli replays SD-card WAVs through the same code.
2026-09-26 firmware: ESP-IDF app - dual-I2S capture, SD logger, NMEA reports
    I2S0 master + I2S1 slave on one clock domain (slave enabled first;
    external jumper or internal GPIO-matrix loopback), capture and DSP
    pinned to separate cores, fixed frame pool, SD writer behind a ring
    buffer with a crash-safe WAV header, $UAVDOA/$UAVCAL sentences.
    Kconfig for node id, M1 heading, FIFO offset, calibration mode.
    Builds for esp32dev (WROOM-32) and esp32s3.
    [app_main.cpp, capture.cpp, sd_logger.cpp]
2026-09-26 docs: research notes, software section in README, CI
    Research on the field (Sky Fortress, Zvook, European vendors),
    datasets, open-source components, and why ESP-IDF over Arduino or
    Rust. README gains the software overview, simulated accuracy, error
    budget and fusion figures, and an updated status. CI runs host C++
    tests, pytest with the parity check, the click-test gate, and both
    firmware builds.
2026-09-26 firmware: clock-return pins match the bench wiring (SCK 14, WS 27)
    The bench bring-up records GPIO14 as the SCK return and GPIO27 as the
    WS return; board_pins.hpp had them the other way round. Also note in
    the firmware README that M3's clock must move onto the shared bus
    before this firmware runs, since 14/27 become I2S1 inputs.
2026-09-27 docs: shorter README and notes, fix inconsistencies
    README cut from 789 to ~360 lines, firmware/analysis READMEs and
    research notes trimmed the same way, chatty code comments shortened.
    Fixed along the way:
    - mic seat: 0.3 mm off-centre is ~0.1 deg by the README's own rule, not 0.06
    - windscreen boss is the 20 mm tip, not 16 mm; lid mass 2.0 g, not 1.5
    - 'do not fit headers' contradicted the pinned boards the pocket is sized for
    - overhang table: case_base window lintels span 14/27 mm (was 3.1 mm)
    - fastener list: 3 x M3x16, the inner nuts belong to the mast fitting
    - schematic note now also mentions the box drawn under the hub
    - noted the I2S run length vs the ground-standing box
    - GCC-PHA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
    [click_test.py, cot_bridge.py]
2026-09-27 docs: README focused on the system; fabrication details to hardware/
    The main README now covers what the device does, how capture stays
    synchronous, accuracy, results, multi-node/TAK use, testing, status and
    limits. Printing, fasteners, lid and box details move to a short
    hardware/README.md together with the bench pin table.
    [click_test.py]
2026-09-27 docs: CI badge and quick start; tidy images
    README gets a CI badge and a short 'Try it' block. hardware/README
    now shows the assembled head, the exploded head, the split arm and the
    box. Four renders nothing referenced (old hub, unlabelled sections, box
    plan) are removed.
